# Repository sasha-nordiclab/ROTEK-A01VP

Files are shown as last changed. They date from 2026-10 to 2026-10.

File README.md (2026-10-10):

# ROTEK A01VP — pump model and accessories

Parametric reference model of the Rotek WPDC-06.7L-10M-24-VP pump (PUM409)
and accessories designed to fit it. The experimental TPU holder is intended
to reduce vibration transfer; its performance has not yet been measured.

The pump reference model and holder are maintained in this repository for use in both
[JOBO Repair Parts](https://github.com/sasha-nordiclab/jobo-repair-parts) and
[THD CP-Lift Parts](https://github.com/sasha-nordiclab/thd-cp-lift-parts).

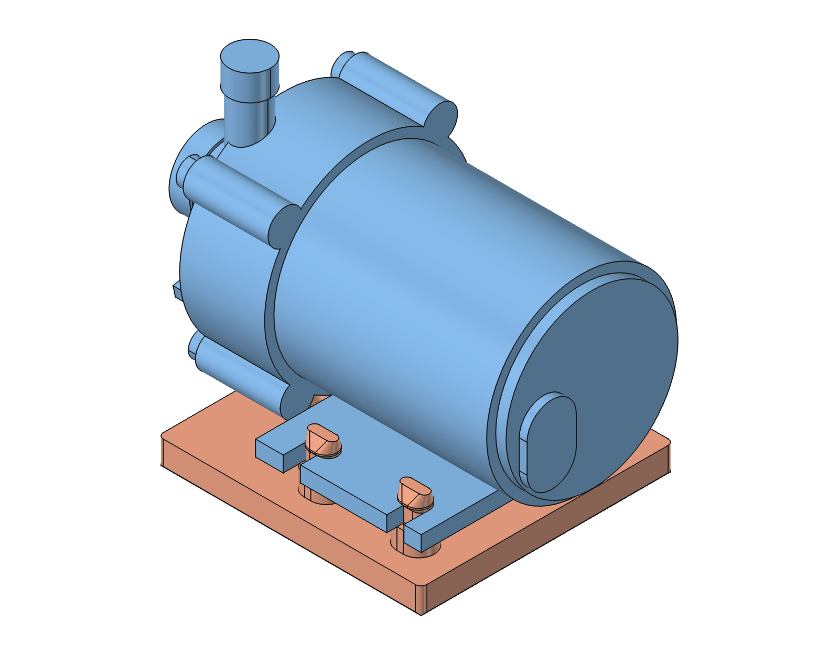
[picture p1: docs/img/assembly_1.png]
Pump on the four-post TPU holder, inlet side
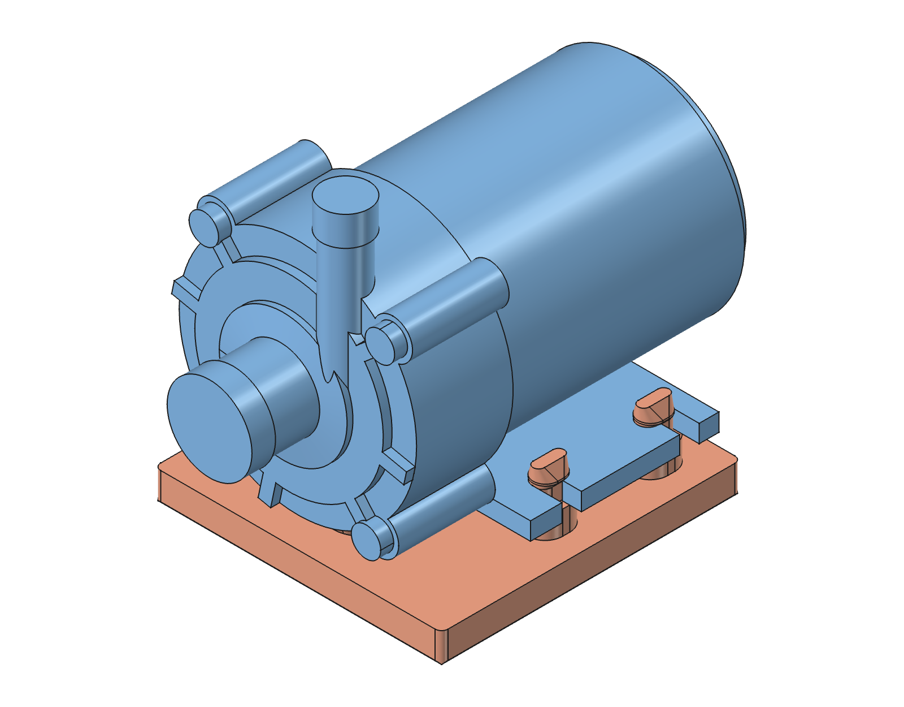
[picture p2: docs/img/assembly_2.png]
Pump on the four-post TPU holder, motor side


## Pump

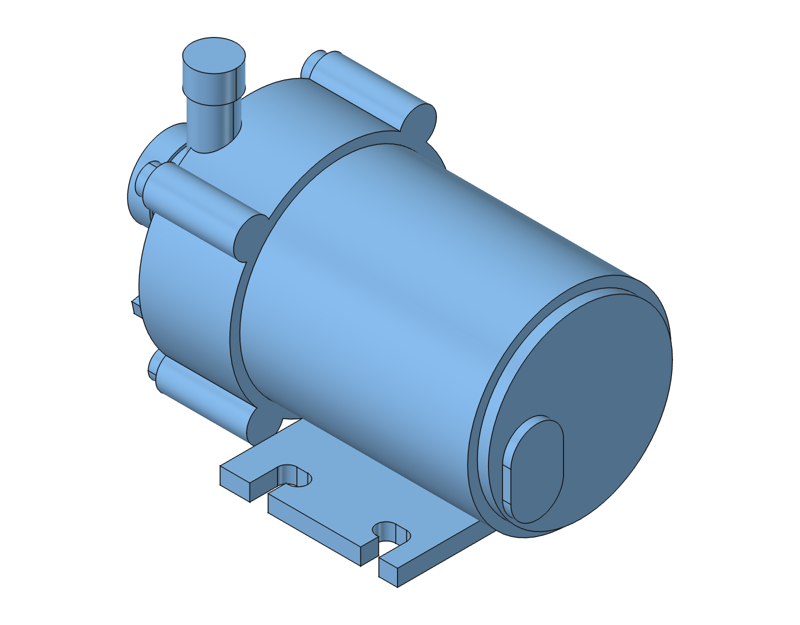
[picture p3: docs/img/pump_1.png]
Pump reference model, motor side
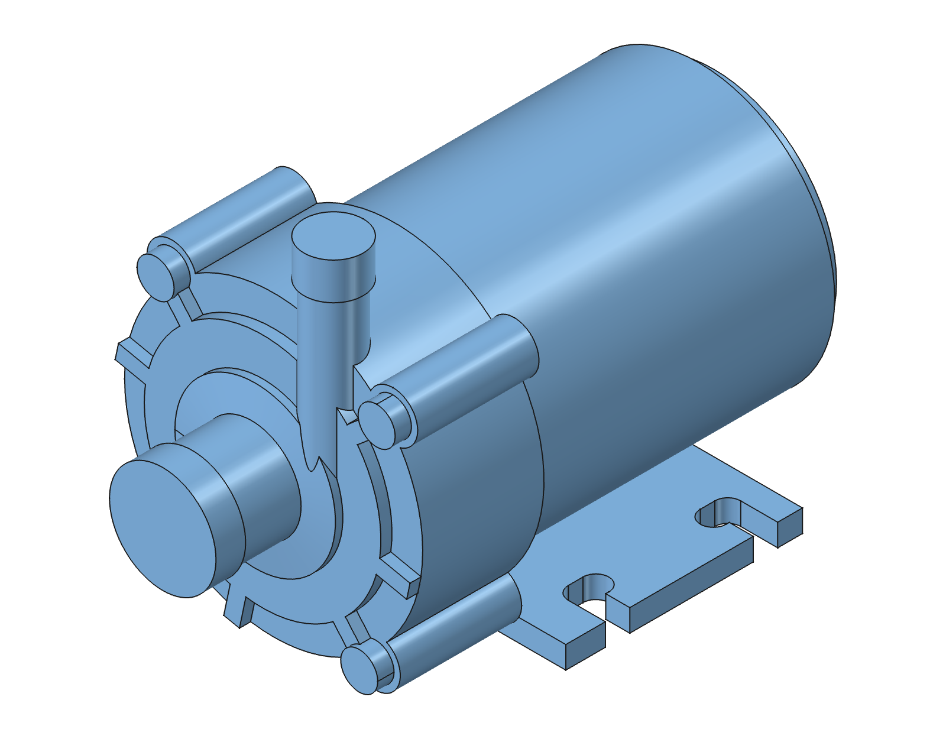
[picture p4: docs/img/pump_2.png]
Pump reference model, inlet side


| | |
|---|---|
| Product | ROTEK Food Grade Mini Centrifugal Pump with Brushless DC Motor |
| Housing | A01VP |
| Supply | 24 VDC |
| Performance | 6.7 L/min or 10 mWs |
| Model | WPDC-06.7L-10M-24-VP (PUM409) |

## Pump and accessory models

**Working model:** [TPU_Pump_Holder.FCStd](cad/TPU_Pump_Holder.FCStd).

- Body **Rotek_WPDC-06.7L-10M-24-VP** is a reference model of the pump, built from the manufacturer's drawing, photos and caliper measurements. Every size is in the `params` spreadsheet.
- Body **Holder** is the experimental four-post stand (see below).

### Coordinates

- Origin: the centre of the four mount slots, on the mounting face of the plate (z = 0).
- X runs along the pump axis, with the inlet towards −X (inlet tip at x = −49).
- Z points from the mounting face into the pump. The pump axis is at `ax_h` = 21.28 mm (from the drawing, not measured yet).
- In the experimental assembly the pump reference Body is placed 4 mm above its original datum, matching `post_h`; its reference dimensions are unchanged. The stand spans z = −5…9.60 mm.

### Mount plate

- 45 × 32 × 3.0 mm, shifted 1.0 mm towards the inlet from the slot pattern: 5.35 mm from the inlet-end edge to the slots, 3.35 mm from the motor-end edge.
- Four L-shaped bayonet slots: the 3.3 mm entry is open to the side edge, and a 3.5 mm wide hook (5.46 mm along the axis, entry included) turns towards the middle of the plate. Slot pitch 20 × 35 mm.
- Sixteen pockets on the mounting face: the centre column is 2.5 mm deep (a 13 mm web to the motor sits behind it), the rest are 1.5 mm deep.

### Symmetry and rebuild

- One slot corner (entry + hook) is modelled; `slots` (MultiTransform, two mirrors) makes the other three.
- The side and outer pockets are modelled on +Y; `pockets_side_mirror` mirrors them across the XZ plane.
- One ear (lug, screw head, partition to the lug) is modelled; `ears` (PolarPattern ×4) repeats it around the datum line `pump_axis`.
- One face partition is modelled; `face_ribs` (PolarPattern ×4) repeats it, with the copy under the outlet suppressed.
- `python3 scripts/build.py` rebuilds the whole document (pump and holder) from scratch in the running FreeCAD in about 10 s; `build.py N` resumes from step N. The `params` sheet gives every value a description and where it came from.
- Pockets on the mounting face are plain rectangles and L shapes (no corner fillets): the holder only touches the frame and the ribs.
- The measurement sheet (`docs/measurements/`, live page linked there) is regenerated by `scripts/measurements/`: `extract_views.py` in FreeCAD, then `build_page.py` and `write_docs.py`.

### Measurements

- Round 1 (2026-10-07): 45 caliper readings, in `docs/measurements/readings.json` and the table in `docs/measurements/measurements.md`. The model follows them within ±0.1 mm (priority A) and ±0.2 mm (priority B), except the rows below.
- Mounting face to the top of the motor (B10, 39.63 mm in the model) is not measured yet, so `ax_h` still comes from the drawing. The ear angle is derived from `ax_h` and the measured height of the highest ear lug: 40.5° now, against 35° on the drawing. B10 settles both.
- Inlet end: the short cone starts 12 mm from the inlet tip, runs 0.5 mm along the axis from Ø13.4 to Ø21.7, then continues as a cylindrical boss. The outlet tube retains its established axial position. The head length follows photo IMG_7253 (16.4 mm); the caliper reading of 14.0 disagrees and is to be measured again.
- Along the axis, B2 + A2 + B3 is 1.0 mm shorter than the overall length B1. Until B17 and B18 are measured, the plate keeps the drawing position: 32 mm from the inlet tip.

The pump reference Body uses origin XY/YZ sketch supports with parameter-driven attachment offsets. Its polar patterns and slot pattern are native FreeCAD features; the pump-axis datum line remains for the polar patterns. The pocket layouts use equality, alignment and horizontal/vertical constraints; radial ribs use named length, width and angle dimensions. These parameterisation changes preserved the pump shape exactly.

## Holder — four-post experiment

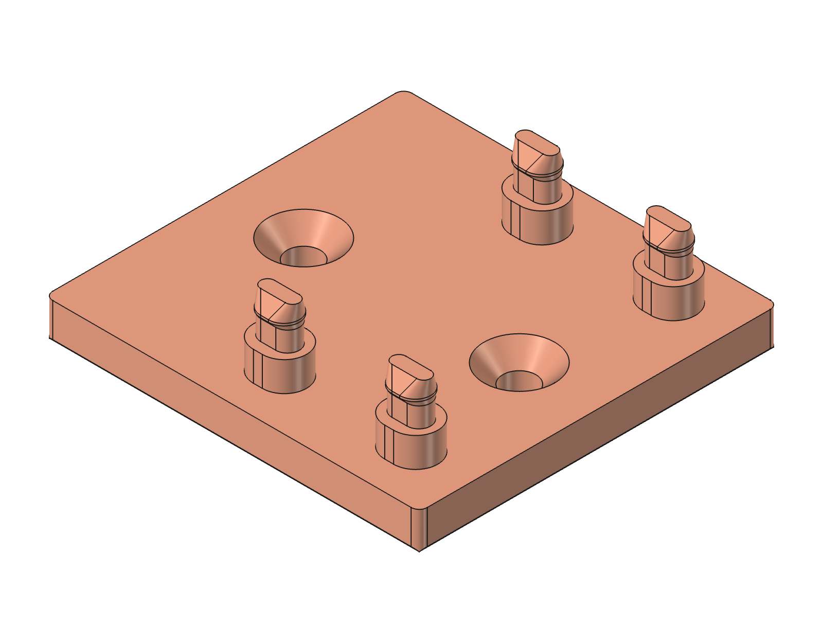
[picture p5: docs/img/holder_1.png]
Four-post TPU holder
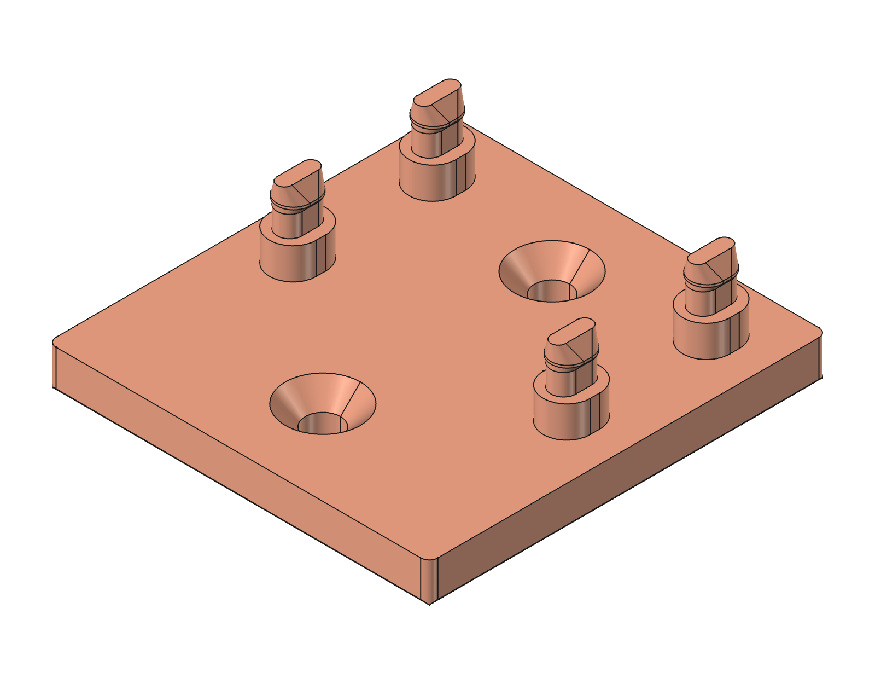
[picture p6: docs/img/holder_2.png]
Four-post TPU holder, other side


A single TPU 95A stand on the bottom of the bath. Its flat floor can be glued down; two M4 holes still allow bolted fixing. Four short columns hold the pump plate 4 mm above the floor. There are no side walls, side lips or entry keys in the final shape.

- Body **Holder** is built by `scripts/build.py`; its dimensions are in the `params` sheet. Its native feature chain is floor Pad, bottom Chamfer, four-corner Fillet, one complete post (column Pad and snap-head AdditiveLoft from five XY-attached, Z-offset sketches) mirrored to four by a single MultiTransform, and a final Hole feature for both M4 countersinks. The obsolete sock features have been removed from the document and build script.
- Floor: 5 mm thick, X = −34…16.9 mm, extended towards the inlet to show the assembly orientation. All four floor corners have a native R1.1 mm Fillet.
- Columns: four oval 7.2 × 6.0 mm posts at X ≈ ±8.92 mm, Y = ±17.5 mm, height `post_h=4` mm. Their top shoulders support the underside of the pump plate.
- Catches: four elongated snap bosses continue above the columns into the hook slots. Stem width 3.2 mm; head width 4.2 mm with a 40° underside and lead-in. Parameter `post_head_pre=0.3 mm` sets a small nominal preload at the plate top. The plate is meant to snap over the heads. Retention against sliding along X without the former keys needs a physical test.
- Mounting holes: two M4 through holes on the floor centreline at X = −23.2 and +6.1 mm, with Ø4.5 mm clearance and 90° Ø9.6 mm countersinks on the pump side.
- Holder bounds: 50.9 × 48.8 × 14.60 mm, z = −5…9.60 mm. The pump and holder are distinct valid solids; their 0.078 mm³ nominal overlap is at the four snap heads.
- Material/profile: AzureFilm TPU, TPU95A Fine, 100 % zig-zag infill. Slicing and snap fit remain untested. A preliminary vibration sensitivity calculation is in [four_post_vibration.md](docs/four_post_vibration.md); actual transmission remains unmeasured.

## Folders

- `cad/` — FreeCAD model.
- `docs/` — notes and calculations.
- `exports/step/` — STEP files of the printed parts.
- `references/` — the manufacturer's drawing and measurement photos.

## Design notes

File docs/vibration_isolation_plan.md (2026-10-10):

# Pump vibration isolation plan

Status: **rejected** in favour of the four-post stand (see [four_post_vibration.md](four_post_vibration.md)). Kept for reference. It was a concept for discussion; the model was not changed for it. The sizes of the compliant elements and their effectiveness were never confirmed by calculation or test.

## What transmits vibration now

- The pump mounting plate (X −17…15, width 45 mm) rests on the solid 5 mm floor of the holder.
- The side walls have only 0.1 mm side clearance; the lips have 0.1 mm interference. The keys and catches that hold the plate are joined to the same floor.
- Two M4 screws fix this pad to the bath. One screw sits under the mounting plate area (X = +6.1 mm), the other in front of it (X = −23.2 mm).
- Removing material only under the plate would therefore leave a parallel vibration path through the walls, lips and catches.

## Proposed layout

Split the part functionally into a fixed base with the M4 screws and the glued face, and an inner pump cradle. The cradle carries a few small supports under the plate, the existing keys and the catches. Leave a gap along its sides to the fixed base; the only intended load path between them is four symmetric compliant TPU bridges. The screws and their heads must not touch the cradle. The two rounded front corners and the orientation cue of the long pad are kept.

For a first prototype a single printed part with bridges is preferable, if the outer outline may grow a little: the side wall already takes almost all the width margin, and at the rear end only 1.9 mm remain to the edge. A fully floating cradle will probably not fit the current outline. If the outline cannot grow, first test a modest relief under the plate with flexible local catches; it will not give full isolation. The alternative is a separate cradle with replaceable elastic connectors. Do not move the holes or the outer outline without agreement.

## Design steps

1. In CAD, mark the fixed zones around both M4 screws, the glued face, the plate outline and the working zones of the keys/catches. Check the room for a gap within the current 50.9 × 48.8 mm outline, especially at the rear end, where only 1.9 mm remain from the plate to the edge.
2. Unload the plate's bearing area: keep small support pads on the cradle and leave a gap under the rest of the plate. Place the supports so that the pump does not rock and does not rest on a screw head.
3. Separate the side retaining elements from the fixed part. Connect them to the base only through the four compliant bridges. Add travel stops with clearance for installation or a tug on a hose; in normal operation the stops do not touch the cradle.
4. Start with a gap of about 1–2 mm between the moving cradle and the fixed base and check it in all three directions. This is a starting range for a mock-up, not a calculated result. Choose bridge thickness, length and shape from the load and a test print, keeping the minimum printable walls.
5. Keep the standard M4 installation and the ability to remove the pump. Check that the screw heads are recessed and do not form a rigid bridge to the cradle, and that the bridges are not under large constant tension or bending after snapping in.
6. Print a comparison sample and test it in the working position under water: bath noise/vibration with the current holder and with the new version, visible cradle travel, settling over time, behaviour at start-up and under hose tension. Water and hoses can also carry vibration around the mount.

## Data needed before tuning stiffness

- The real mass of the pump with connected hoses and the direction of its load in the working position; under water the weight drops because of buoyancy.
- Rotation speed / main vibration frequencies at nominal supply (or a vibration recording on the housing and the bath).
- The allowed growth of the holder outline and height, and the desired travel margin when snapping in.

Principle: isolation depends on the ratio of the excitation frequency to the natural frequency of the system and on the stiffness/load of the supports. A smaller contact area alone does not guarantee improvement, and supports that are too stiff can transmit almost all of the vibration. See the [Sorbothane guide to choosing isolators](https://www.sorbothane.com/technical-data/articles/how-to-select-a-standard-sorbothane-isolator/) and the [engineering design guide](https://www.sorbothane.com/wp-content/uploads/Sorbothane-EDG.pdf). These sources describe the principle; their numeric material properties must not be applied to printed TPU 95A.

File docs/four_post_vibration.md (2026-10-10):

# Four-post stand: preliminary vibration estimate

The model in `experiment/four-post-stand` holds the pump plate 4 mm above a glued floor on four straight TPU columns. This calculation checks the load path before printing. It is a linear, dry, one-mass estimate, not a measurement or FEM validation. The initial 12 mm prototype was shortened at the user's request.

## Inputs

| Quantity | Value | Status |
|---|---:|---|
| Pump plus working hoses | 0.280 kg | User measurement |
| Number of columns | 4 | CAD |
| Column capsule footprint | 7.2 × 6.0 mm | CAD, `post_l`, `post_w` |
| Free column height | 4.0 mm | CAD, `post_h` |
| Section area | 35.474 mm² each | Calculated from capsule |
| Dynamic Young modulus | 5, 15, 30, 60 MPa | Scenarios; **not** measured for this filament/print |
| Damping ratio | 0.15 | Scenario; **not** measured |

The [AzureFilm TPU 95A product page](https://azurefilm.com/product/tpu-flexible-95a-blue/) describes the material qualitatively but does not supply a dynamic modulus or damping curve for the printed part. Therefore the modulus and damping values above are a sensitivity sweep, not material specifications.

## Method

For a vertical force carried in compression by all four equal columns, `kz = 4 E A / h`. With mass `m`, `fn = sqrt(1000 kz / m)/(2π)` for `kz` in N/mm. Dry static deflection is `mg/kz`. The force transmissibility for a linear damped isolator is `T = sqrt((1 + (2ζr)²) / ((1-r²)² + (2ζr)²))`, with `r = f/fn`. Isolation (`T < 1`) begins only when `f > sqrt(2) fn`; see the [FIU/Rao vibration isolation handout](https://web.eng.fiu.edu/LEVY/images/EML3222/EML3222-Rao%20Handout.pdf).

| Assumed E | Vertical stiffness | Vertical fn | Dry sag | T at 50 Hz | T at 100 Hz | T at 200 Hz |
|---:|---:|---:|---:|---:|---:|---:|
| 5 MPa | 177.4 N/mm | 126.7 Hz | 0.0155 mm | 1.18 | 2.31 | 0.71 |
| 15 MPa | 532.1 N/mm | 219.4 Hz | 0.0052 mm | 1.05 | 1.26 | 3.22 |
| 30 MPa | 1064.2 N/mm | 310.3 Hz | 0.0026 mm | 1.03 | 1.11 | 1.65 |
| 60 MPa | 2128.5 N/mm | 438.8 Hz | 0.0013 mm | 1.01 | 1.05 | 1.26 |

`T > 1` means more force reaches the glued base than the motor's applied harmonic force at that frequency. At the mid-range example `E=15 MPa`, isolation begins above about 310 Hz. The four thick straight columns do not provide reliable low-frequency vertical isolation; their static compression is only about 0.005 mm in this example. Reaching `fn≈30 Hz` at the same area and modulus would require a column height around 214 mm, so tuning this concept by post height alone is impractical. At 100 Hz, the shorter posts reduce the calculated resonance amplification from 2.31 to 1.26, but at 200 Hz they increase it from 0.71 to 3.22. Neither result is an actual pump operating point.

For horizontal bending, the capsule has `Ixx=85.217 mm⁴` and `Iyy=117.860 mm⁴`. With `E=15 MPa`, a cantilever estimate gives first lateral frequencies of 173 Hz in X and 147 Hz in Y. If the pump plate fully constrains the column tips against rotation, they rise to about 346 and 295 Hz. The real assembly lies somewhere between those ideal boundary conditions and may rock. These lateral values are less certain than the axial values.

## Limits and next check

- The pump vibration frequency at operating voltage is unknown; do not label a particular table column as the actual operating point.
- Water, buoyancy, moving water in the pump, hoses, glue compliance, print direction and TPU viscoelasticity are omitted. Hoses can bypass the stand and carry vibration directly to the bath.
- The calculated vertical stiffness applies to compression into the post shoulders. Upward force is caught by the snap heads and has a different, nonlinear load path. `post_head_pre=0.3 mm` creates a small nominal head/plate interference in CAD (0.078 mm³ total over four heads), but real preload and snap force require a print test.
- Check the vibration frequency and acceleration on the pump and bath in water, and check whether the plate can slide along the slot entries without the old side keys.

Recompute the table with `python3 scripts/post_vibration_estimate.py`.

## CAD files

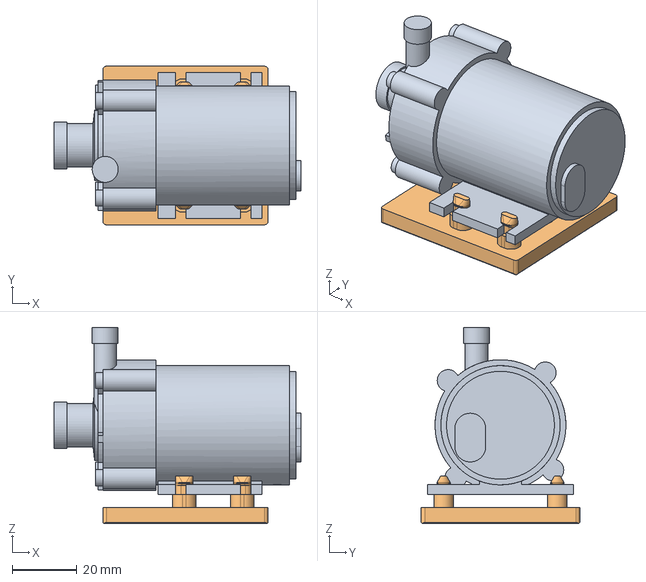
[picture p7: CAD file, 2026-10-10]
cad/TPU_Pump_Holder.FCStd
76.0 x 48.8 x 60.4 mm
Rotek_WPDC-06.7L-10M-24-VP
Holder

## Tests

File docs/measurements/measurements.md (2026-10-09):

# Pump measurement sheet

Numbered dimensions of the `Pump` reference model in `cad/TPU_Pump_Holder.FCStd`, checked against the real Rotek WPDC-06.7L pump.
The live sheet with input fields is at https://claude.ai/artifact/8BBLBfdxXsbRfHfFudTgku; values typed there are saved and read back to correct the model.
Readings below: round 1, 2026-10-07.

## How to measure

- **Heights:** stand the pump on a flat table with the mounting face down and measure from the table with the depth rod, or with outside jaws from the plate frame.
- **Lengths along the pump:** from the tip of the inlet barb.
- **Priority A** rows shape the holder (plate, slots, outer size, outlet, cable); **B** rows refine the shape.
- **Tolerance:** ±0.10 mm for A, ±0.20 mm for B. Δ is the reading minus the model; ✗ marks a Δ past tolerance. Rows marked *check* are to measure next.

## A — Mounting face (seen from the wall side, inlet to the left)

View A

| ID | Prio | Dimension | How | Model | Drawing | Reading | Δ | Source |
|---|---|---|---|---|---|---|---|---|
| A1 | A | Plate width, across the slotted edges | Outside jaws | 45 | 45 | 45 | +0.00 | caliper 44.93, 45.0 |
| A2 | A | Plate length along the pump axis | Outside jaws | 32 | 32 | 32 | +0.00 | caliper 32.03, 32.0 |
| A3 | A | Slot pitch along the axis, centre to centre | Inside jaws across the outer walls of two slots on one edge, minus A5 | 20 | 20 | 20 | +0.00 | caliper 20.0 |
| A4 | A | Slot depth: side edge to the inner end of the slot | Depth rod from the side edge | 6.75 | 6.65 | 6.85 | +0.10 | caliper 6.85 (earlier 6.30, 6.59) |
| A5 | A | Slot width at the entry, at the plate edge | Inside jaws | 3.3 | 3.3 | 3.4 | +0.10 | caliper 3.37, 3.39, 3.40 |
| A6 | A | Slot width in the hook | Inside jaws | 3.5 | 3.3 | 3.5 | +0.00 | caliper 3.5 |
| A7 | A | Slot length along the axis, hook included | Inside jaws | 5.46 | 5.2 | 5.46 | +0.00 | caliper 5.46 |
| A8 | A | Motor-end edge of the plate to the nearest slot wall | Depth rod from the plate end | 3.35 | 3.35 | 3.45 | +0.10 | caliper 3.45 |
| A9 | A | Inlet-end edge of the plate to the nearest slot wall | Depth rod from the plate end | 5.35 | 5.35 | 5.5 | +0.15 ✗ | caliper 5.5; A8 + A9 + the slots run 0.25 over A2 |
| A10 | B | Frame at the inlet end, edge to the first pocket | Depth rod | 1.5 | — | 1.5 | +0.00 | caliper 1.5 |
| A11 | B | Pocket length along the axis, three inlet-side rows | Inside jaws | 6.3 | — | — |  | photo — *check* |
| A12 | B | Rib between two pockets | Outside jaws | 1.8 | — | — |  | photo — *check* |
| A13 | B | Pocket length, motor-end row | Inside jaws | 4.6 | — | 4.5 | -0.10 | caliper 4.5 |
| A14 | B | Frame at the motor end, edge to the last pocket | Depth rod | 1.6 | — | 1.5 | -0.10 | caliper 1.5 |
| A15 | B | Centre pocket width | Inside jaws | 10.2 | — | — |  | photo |
| A16 | B | Width of the pockets next to the centre ones | Inside jaws | 4.3 | — | 4.3 | +0.00 | caliper 4.3 |
| A17 | B | Outer pocket width, towards the slotted edge | Inside jaws | 8.1 | — | — |  | photo |
| A18 | B | Frame along the slotted edge | Depth rod | 1.4 | — | 1.5 | +0.10 | caliper 1.5 |
| A19 | B | Outer pocket, inlet side: length of the part beside the hook | Inside jaws | 3.29 | — | — |  | photo — *check* |
| A20 | B | Outer pocket, motor side: length of the part beside the hook | Inside jaws | 3.69 | — | 4 | +0.31 ✗ | caliper 4.0, off by 0.3 after the plate shift — *check* |
| A21 | A | Depth of the four centre pockets | Depth rod | 2.5 | — | 2.5 | +0.00 | caliper 2.5 |
| A22 | A | Depth of the other pockets | Depth rod | 1.5 | — | 1.5 | +0.00 | caliper 1.5 |

## B — Side (mounting face on the table, outlet up)

View B

| ID | Prio | Dimension | How | Model | Drawing | Reading | Δ | Source |
|---|---|---|---|---|---|---|---|---|
| B1 | A | Overall length: inlet tip to the motor end face, grommet excluded | Outside jaws | 74.5 | 75 | 74.5 | +0.00 | caliper 74.5 |
| B2 | A | Inlet tip to the inlet-end edge of the plate | Depth rod or outside jaws | 32 | 32 | 31.5 | -0.50 ✗ | caliper 31.5; B2 + A2 + B3 is 1.0 short of B1 — *check* |
| B3 | A | Motor-end edge of the plate to the motor end face | Depth rod from the plate end | 10.5 | 11 | 10 | -0.50 ✗ | caliper 10.0 and 10.22; see B2 — *check* |
| B4 | B | Inlet tip to the ear-lug face, under the screw heads | Depth rod or outside jaws | 15 | — | 15 | +0.00 | caliper 15.0; photo IMG_7253 15.0 |
| B5 | B | Inlet tip to the face of the Ø32 cover | Depth rod or outside jaws | 13.5 | — | — |  | guess — *check* |
| B6 | B | Head length: ear-lug face to the joint with the motor | Outside jaws | 16.4 | 15.5 | 14 | -2.40 ✗ | photo 16.4; caliper 14.0 disagrees — *check* |
| B7 | B | Inlet barb length (the Ø14.4 part) | Outside jaws | 4 | 4 | 4 | +0.00 | caliper 4.0 |
| B8 | B | Straight neck length (the Ø13.4 part) | Outside jaws | 8 | 7 | 8.2 | +0.20 | 12 mm from inlet tip to cone start, minus 4 mm inlet barb; earlier caliper 8.2 |
| B9 | B | Neck diameter | Outside jaws | 13.4 | 13.4 | 13.5 | +0.10 | caliper 13.5 |
| B10 | A | Mounting face to the top of the motor (gives the axis height) | Outside jaws from the plate frame over the motor | 39.63 | — | — |  | not measured — *check* |
| B11 | A | Table to the top of the highest ear lug | From the table, depth rod | 40.75 | — | 40.75 | +0.00 | caliper 40.75; drawing 42 |
| B12 | A | Table to the outlet tip | From the table, depth rod | 51.4 | 52 | 51.4 | +0.00 | caliper 51.4 |
| B13 | B | Inlet tip to the outlet axis | Outside jaws to the near side of the outlet, plus half of C13 | 15.75 | 16.5 | — |  | outlet position retained from the established model |
| B14 | B | Outlet barb length (the Ø8 part) | Outside jaws | 5 | 5 | 5 | +0.00 | caliper 5.0 |
| B15 | B | Step at the motor end: shoulder to the end face | Depth rod | 2 | — | 2 | +0.00 | caliper 2.0 |
| B16 | B | Grommet height above the motor end face | Depth rod | 1.5 | — | — |  | guess |
| B17 | A | Inlet tip to the motor-end edge of the plate | Outside jaws, jaws from the mounting-face side | 64 | 64 | — |  | new: cross-checks B2 — *check* |
| B18 | A | Inlet-end edge of the plate to the motor end face | Outside jaws, jaws from the mounting-face side | 42.5 | 43 | — |  | new: cross-checks B3 — *check* |

## C — Inlet end

View C

| ID | Prio | Dimension | How | Model | Drawing | Reading | Δ | Source |
|---|---|---|---|---|---|---|---|---|
| C1 | A | Head diameter | Outside jaws | 40.3 | 40 | 40.29 | -0.01 | caliper 40.29 |
| C2 | B | Diameter of the raised Ø32 cover | Outside jaws | 31.99 | 32 | 31.99 | +0.00 | caliper 31.99 |
| C3 | B | Diameter of the boss (mini flange) around the inlet | Outside jaws | 21.7 | 23 | — |  | photo 22.3; model keeps it tangent to the outlet tube — *check* |
| C4 | B | Inlet barb diameter | Outside jaws | 14.4 | 14.4 | — |  | drawing |
| C5 | A | Across two opposite ear lugs, outer edges | Outside jaws | 49.1 | 49.1 | 49 | -0.10 | caliper 49.0 |
| C6 | B | Ear lug width | Outside jaws | 6.7 | 6.7 | 6.8 | +0.10 | caliper 6.8 |
| C7 | A | Table to the top of the lower screw head, side away from the outlet | From the table, depth rod | 10.01 | — | — |  | not measured (checks the ear angle) — *check* |
| C8 | A | Table to the top of the lower screw head, outlet side | From the table, depth rod | 7.66 | — | — |  | not measured (checks the ear angle) — *check* |
| C9 | B | Partition width | Outside jaws | 2.17 | — | 2.17 | +0.00 | caliper 2.17 |
| C10 | B | Partition height above the recessed segments | Depth rod | 1.5 | — | 1.5 | +0.00 | caliper 1.5 |
| C11 | A | Far side of the outlet tube to the opposite side of the head | Outside jaws | 31 | — | 31 | +0.00 | caliper 31.0 |
| C12 | B | Outlet barb diameter | Outside jaws | 8 | 8 | 8 | +0.00 | caliper 8.0 |
| C13 | B | Outlet tube diameter below the barb | Outside jaws | 7 | 7 | 6.9 | -0.10 | caliper 6.9 |
| C14 | B | Screw head diameter | Outside jaws | 5 | — | 5 | +0.00 | caliper 5.0 |
| C15 | B | Screw head height above the ear lug | Depth rod | 2.2 | — | 2 | -0.20 | caliper 2.0 |

## D — Motor end

View D

| ID | Prio | Dimension | How | Model | Drawing | Reading | Δ | Source |
|---|---|---|---|---|---|---|---|---|
| D1 | A | Motor diameter | Outside jaws | 36.7 | — | 36.72 | +0.02 | caliper 36.72 |
| D2 | B | Diameter of the motor end face (inside the step) | Outside jaws | 33.2 | — | 33.2 | +0.00 | caliper 33.2 |
| D3 | A | Motor side (outlet side) to the centre of the wire hole | Depth rod or outside jaws | 9.05 | — | — |  | photo — *check* |
| D4 | B | Grommet length | Outside jaws | 15 | — | 15 | +0.00 | caliper 15.0 |
| D5 | B | Grommet width | Outside jaws | 9.5 | — | 9.5 | +0.00 | caliper 9.5 |
| D6 | A | Table to the centre of the wire hole | From the table, depth rod | 21.28 | — | — |  | photo — *check* |
| D7 | A | Plate thickness at the edge | Outside jaws | 3 | 3.5 | 3 | +0.00 | caliper 2.98, 3.0 |
| D8 | B | Width of the web between the plate and the motor | Outside jaws | 13 | — | — |  | guess |

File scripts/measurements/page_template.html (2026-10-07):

Measurement sheet

# Rotek WPDC-06.7L pump

Measure each numbered dimension on the real pump and type it in. Values save as you type. Claude reads them and corrects the model.

PartPump (reference)

ModelTPU_Pump_Holder.FCStd

Unitsmm

Rows—

Tolerance A±0.10

Tolerance B±0.20

ToolCaliper ±0.05

Revision1

### Heights

Stand the pump on a flat table with the mounting face down. Measure every height from the table with the depth rod. The ribs rest on the table, so the pockets don't matter.

### Lengths

Lengths along the pump run from the tip of the inlet barb, the part straight on the axis.

### Priority

A rows shape the holder: mounting plate, slots, outer size, outlet and cable. Do them first. B rows refine the shape.

### Δ colours

Δ is your value minus the model. Green is within tolerance, amber is up to 3× tolerance, red is more. Rows marked check disagree with the drawing or with an earlier reading.

Loading saved values…

All Priority A Not measured Check first

A

## Mounting face

Seen from the wall side, inlet to the left. Slots, plate edges and the pocket grid. Dashed circles are depths.

B

## Side

Mounting face on the table, outlet up, inlet to the left. Lengths along the pump and heights from the table.

C

## Inlet end

Looking at the inlet, mounting face on the table. Head, cover, ear lugs, partitions and the outlet offset.

D

## Motor end

Looking at the motor end, mounting face on the table. Motor, end step, grommet and the plate edge.

Drawings are projections of the current FreeCAD model. Model values update when Claude revises the model; your entries stay.

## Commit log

2026-10-06 Pump reference model: Rotek WPDC-06.7L from the drawing, photos and caliper readings
    Body Pump with every size in params; origin at the centre of the mount slots
    on the mounting face. Mount plate 45x32x3 with L-shaped bayonet slots and
    waffle pockets (centre column 2.5 deep, the rest 1.5), head with the Ø32
    cover and the partitions, ear lugs with screw heads, inlet, outlet and the
    cable grommet. Reference drawing and measurement photos in references/.
    [TPU_Pump_Holder.FCStd]
2026-10-07 Pump reference model v1: clean symmetric rebuild and measurement sheet
    - scripts/build_pump.py rebuilds the Pump body from scratch through fdmkit.
    Symmetry is native PartDesign: one slot corner + MultiTransform (two
    mirrors), +Y pockets + Mirrored, one ear (lug, screw head, partition) +
    PolarPattern x4 around the pump_axis datum line, one face partition +
    PolarPattern x4 with the copy under the outlet suppressed.
    - Mount plate symmetric about the slots (33..65 mm from the inlet tip),
    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
    [TPU_Pump_Holder.FCStd]
2026-10-07 Rotek WPDC-06.7L-10M-24-VP reference model after measurement round 1
    - Body named Rotek_WPDC-06.7L-10M-24-VP; README lists the pump (A01VP housing, 24 VDC, 6.7 L/min or 10 mWs).
    - 45 caliper readings applied (docs/measurements/readings.json): plate offset 1.0 towards the inlet, hook width 3.5, length 74.5, outlet tip 51.4, outlet offset 7.35, motor step, grommet, pockets.
    - Inlet end: no cone, the outlet tube is tangent to the boss with its front flush with the boss face, head from 15.0 to 31.4.
    - Axis height kept from the drawing until B10 is measured; ear angle is derived from it.
    - Measurement sheet: cross-check rows B17/B18, write_docs.py for the docs table.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
    [TPU_Pump_Holder.FCStd]
2026-10-09 Add TPU pump holder and describe shared A01VP accessories repository
    [TPU_Pump_Holder.FCStd]
2026-10-09 Extend TPU snap bosses along hook slots
    [TPU_Pump_Holder.FCStd]
2026-10-09 Remove protruding corner stops from TPU holder
    [TPU_Pump_Holder.FCStd]
2026-10-09 Move outlet nozzle forward to tangent head face
    [TPU_Pump_Holder.FCStd]
2026-10-09 Restore outlet position and taper inlet boss
    [TPU_Pump_Holder.FCStd]
2026-10-09 Limit inlet cone to 0.5 mm after 12 mm neck
    [TPU_Pump_Holder.FCStd]
2026-10-09 Document pump holder state for AI handoff
2026-10-09 Restore overall model view after CAD work
2026-10-09 Apply saturated pastel colors to pump and holder
2026-10-09 Extend holder floor and add countersunk M4 mounts
2026-10-09 Plan compliant pump isolation architecture
2026-10-09 Restore current pre-isolation holder model on main
    [TPU_Pump_Holder.FCStd]
2026-10-09 Prototype four-post snap stand and estimate vibration transfer
    [TPU_Pump_Holder.FCStd]
2026-10-10 Shorten four-post stand to 4 mm air gap
    [TPU_Pump_Holder.FCStd]
2026-10-10 Clean four-post holder feature tree
    [TPU_Pump_Holder.FCStd]
2026-10-10 Use native chamfer on holder base
    [TPU_Pump_Holder.FCStd]
2026-10-10 Round all four holder floor corners
    [TPU_Pump_Holder.FCStd]
2026-10-10 Pattern complete support posts as one feature set
    [TPU_Pump_Holder.FCStd]
2026-10-10 Attach snap head sections directly to XY plane
    [TPU_Pump_Holder.FCStd]
2026-10-10 Simplify pump reference sketch supports
    [TPU_Pump_Holder.FCStd]
2026-10-10 Constrain pump pockets and ribs geometrically
    [TPU_Pump_Holder.FCStd]
2026-10-10 Add README renders and translate notes to English
    Render the pump on the four-post holder and the holder alone from the
    FreeCAD model (white background, pastel colours) into docs/img and show
    them in the README. Translate the AI handoff (AGENTS.md) and the rejected
    vibration isolation plan to English and mark the plan as rejected.
2026-10-10 Export README images from FreeCAD and add pump-only views
    [TPU_Pump_Holder.FCStd]
2026-10-10 Centre README images and add export script
    fitAll frames the bounding sphere, which left the models off-centre with
    uneven margins. scripts/readme_images.py centres the camera on the projected
    shape and fills 88 % of the frame before View3D.saveImage.
    [TPU_Pump_Holder.FCStd]
